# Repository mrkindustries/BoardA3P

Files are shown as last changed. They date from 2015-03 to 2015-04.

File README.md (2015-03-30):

BoardA3PU
=============

## Arduino-compatible FPGA board

## Schematic
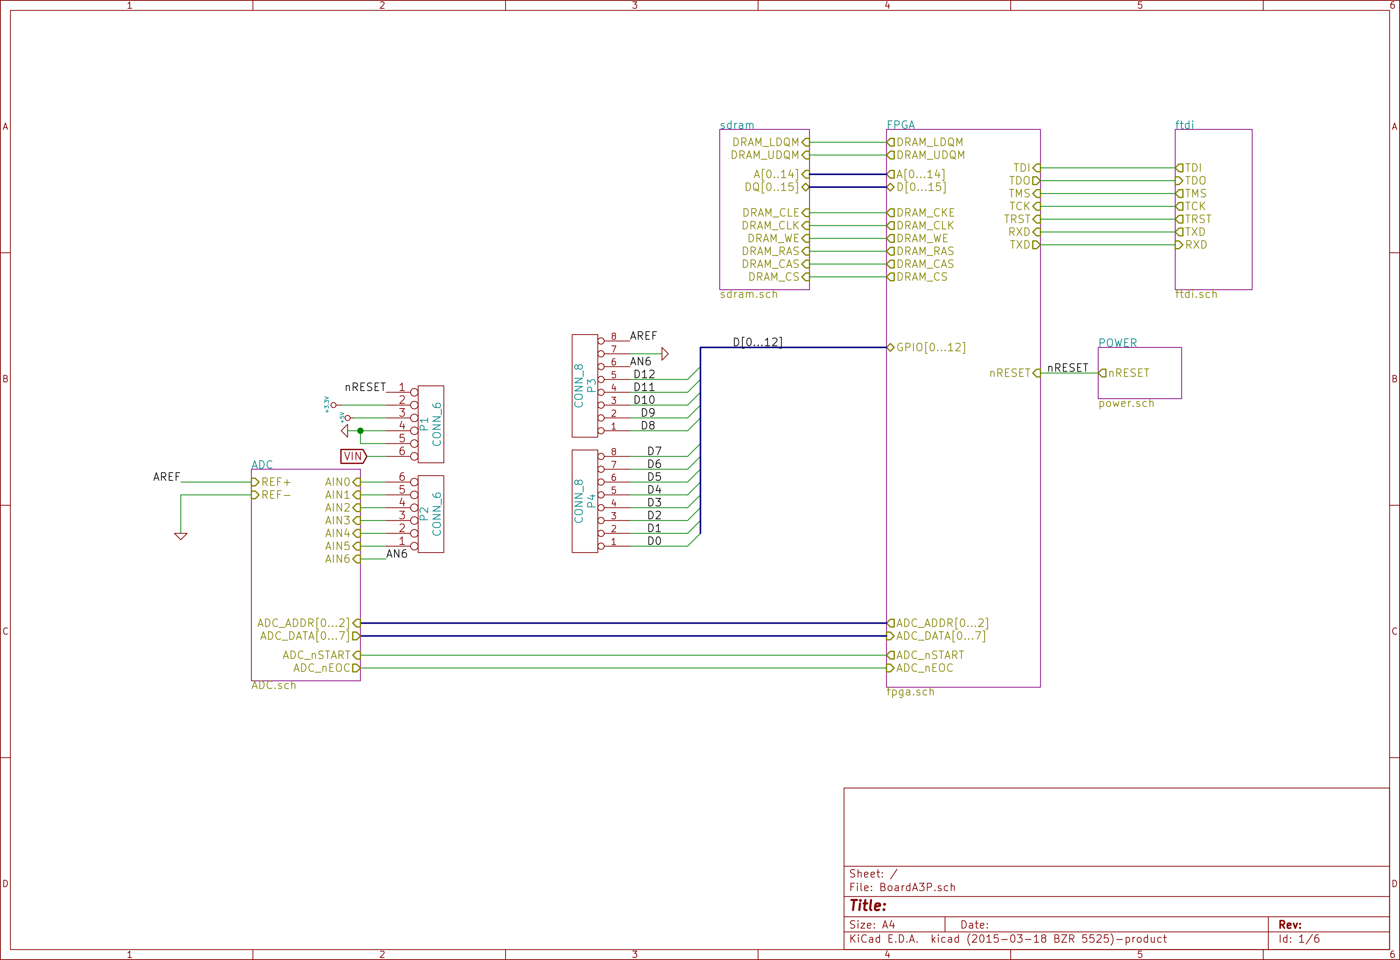
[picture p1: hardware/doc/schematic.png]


## 3D views
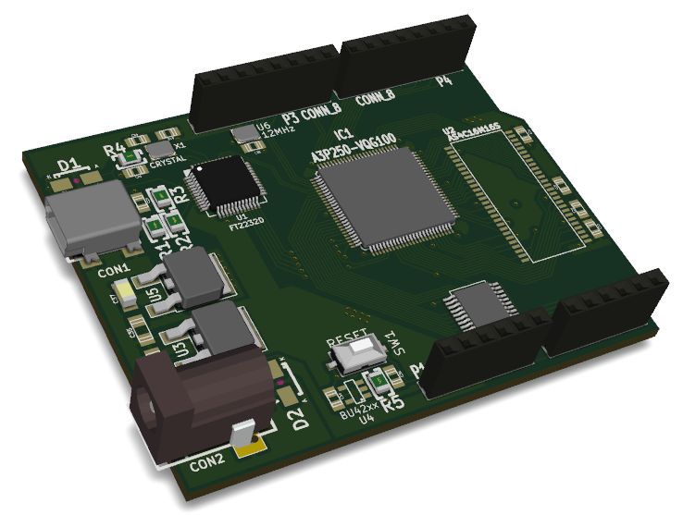
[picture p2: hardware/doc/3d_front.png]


This board was designed using kicad, you can find the CAD files in the /hardware/design folder
http://www.kicad-pcb.org

Download the schematic

[schematic.pdf](/hardware/doc/schematic.pdf?raw=true)

**Warning:** untested until the first prototype arrives

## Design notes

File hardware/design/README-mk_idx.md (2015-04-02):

mk_idx.py
=========

Create index HTML file with references to sheets

Required
========

  * python 2.7 
  * inkscape

Usage
=====

  * Export schematic as svg files
  * Run ```python mk_idx.py <top-schematic.sch>``` into exported image directory

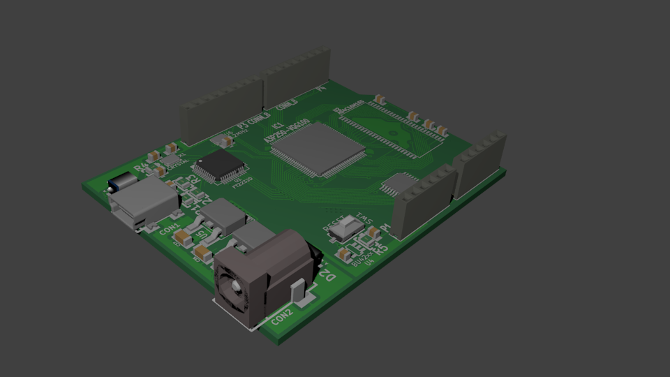
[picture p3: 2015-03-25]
hardware/doc/BoardA3P.png

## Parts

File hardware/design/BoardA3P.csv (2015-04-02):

Reference | Value | Footprint | Unit Price | Digi Code
P1 | PPTC081LFBN-RC | Connect:SIL-6 | 0,68 | S7004-ND
P3 | PPTC081LFBN-RC | Connect:SIL-8 | 0,68 | S7004-ND
P4 | PPTC081LFBN-RC | Connect:SIL-8 | 0,86 | S7006-ND
P2 | PPTC081LFBN-RC | Connect:SIL-6 | 0,86 | S7006-ND
IC1 | A3PN250-VQG100 | SMD_Packages:VQFP100 | 14,96 | 1100-1042-ND
C3 | 100n | Capacitors_SMD:c_0805 | 0,1 | 1276-1007-1-ND
C4 | 100n | Capacitors_SMD:c_0805 | 0,1 | 1276-1007-1-ND
C5 | 100n | Capacitors_SMD:c_0805 | 0,1 | 1276-1007-1-ND
C6 | 100n | Capacitors_SMD:c_0805 | 0,1 | 1276-1007-1-ND
C7 | 100n | Capacitors_SMD:c_0805 | 0,1 | 1276-1007-1-ND
C8 | 100n | Capacitors_SMD:c_0805 | 0,1 | 1276-1007-1-ND
C10 | 100n | Capacitors_SMD:c_0805 | 0,1 | 1276-1007-1-ND
C11 | 100n | Capacitors_SMD:c_0805 | 0,1 | 1276-1007-1-ND
C12 | 100n | Capacitors_SMD:c_0805 | 0,1 | 1276-1007-1-ND
C13 | 100n | Capacitors_SMD:c_0805 | 0,1 | 1276-1007-1-ND
C14 | 10n | Capacitors_SMD:c_0805 | 0,1 | 490-1664-1-ND
C15 | 10n | Capacitors_SMD:c_0805 | 0,1 | 490-1664-1-ND
C16 | 10n | Capacitors_SMD:c_0805 | 0,1 | 490-1664-1-ND
C17 | 10n | Capacitors_SMD:c_0805 | 0,1 | 490-1664-1-ND
C9 | 100n | Capacitors_SMD:c_0805 | 0,1 | 1276-1007-1-ND
C2 | 10n | Capacitors_SMD:c_0805 | 0,1 | 490-1664-1-ND
C1 | 33u | Capacitors_SMD:c_0805 | 0,88 | 445-4060-1-ND
U6 | 12MHz | local:OSC_2x2p5
C38 | 100n | Capacitors_SMD:c_0805 | 0,1 | 1276-1007-1-ND
U1 | FT2232D | Housings_QFP:lqfp-48 | 6,99 | 768-1010-1-ND
CON1 | USB-MINI-B | Connect:USB_MINI_B
C20 | 33n | Capacitors_SMD:c_0805 | 0,1 | 1276-1796-1-ND
C23 | 100n | Capacitors_SMD:c_0805 | 0,1 | 1276-1007-1-ND
C24 | 100n | Capacitors_SMD:c_0805 | 0,1 | 1276-1007-1-ND
C22 | 10u | Capacitors_SMD:c_1206 | 0,19 | 399-1299-1-ND
R4 | 470R | Resistors_SMD:Resistor_SMD0805_ReflowWave | 0,1
C21 | 100n | Capacitors_SMD:c_0805 | 0,1 | 1276-1007-1-ND
C25 | 100n | Capacitors_SMD:c_0805 | 0,1 | 1276-1007-1-ND
R1 | 27R | Resistors_SMD:Resistor_SMD0805_ReflowWave | 0,1
R2 | 27R | Resistors_SMD:Resistor_SMD0805_ReflowWave | 0,1
R3 | 1K5 | Resistors_SMD:Resistor_SMD0805_ReflowWave | 0,1
X1 | 6Mhz | Crystals_Oscillators_SMD:crystal_FA238-TSX3225
C18 | 33n | Capacitors_SMD:c_0805 | 0,1 | 1276-1796-1-ND
C19 | 33n | Capacitors_SMD:c_0805 | 0,1 | 1276-1796-1-ND
D1 | S1G | Diodes_SMD:Diode-SMA_Standard | 0,42
U2 | AS4C16M16S | local:TSOP_II_54 | 2,84 | 1450-1145-ND
C26 | 100n | Capacitors_SMD:c_0805 | 0,1 | 1276-1007-1-ND
C27 | 100n | Capacitors_SMD:c_0805 | 0,1 | 1276-1007-1-ND
C28 | 100n | Capacitors_SMD:c_0805 | 0,1 | 1276-1007-1-ND
C29 | 100n | Capacitors_SMD:c_0805 | 0,1 | 1276-1007-1-ND
C30 | 100n | Capacitors_SMD:c_0805 | 0,1 | 1276-1007-1-ND
C31 | 100n | Capacitors_SMD:c_0805 | 0,1 | 1276-1007-1-ND
C32 | 100n | Capacitors_SMD:c_0805 | 0,1 | 1276-1007-1-ND
CON2 | BARREL_JACK | Connect:BARREL_JACK
U5 | NCP1117ST15T3G | SMD_Packages:DPAK2 | 0,45 | NCP1117DT15RKGOSCT-ND
U3 | NCP1117ST33T3G | SMD_Packages:DPAK2 | 0,49 | NCP1117DT33RKGOSCT-ND
C35 | 4u7 | Capacitors_SMD:c_1206 | 0,2 | 1276-1191-1-ND
C37 | 4u7 | Capacitors_SMD:c_1206 | 0,2 | 1276-1191-1-ND
C33 | 10u | Capacitors_SMD:c_1206 | 0,19 | 399-1299-1-ND
U4 | BU42xx | local:SSOP-5
C34 | 100n | Capacitors_SMD:c_0805 | 0,1 | 1276-1007-1-ND
SW1 | RESET | switchs:smd_push
R5 | 10k | Resistors_SMD:Resistor_SMD0805_ReflowWave | 0,1
C36 | 1u | Capacitors_SMD:c_0805 | 0,1 | 1276-1246-1-ND
D2 | S1G | Diodes_SMD:Diode-SMA_Standard | 0,42
U7 | MAX117 | SMD_Packages:SSOP28 | 7,03 | MAX117CAI+-ND
C40 | 100n | Capacitors_SMD:c_0805 | 0,1 | 1276-1007-1-ND
 |  |  | 42,24

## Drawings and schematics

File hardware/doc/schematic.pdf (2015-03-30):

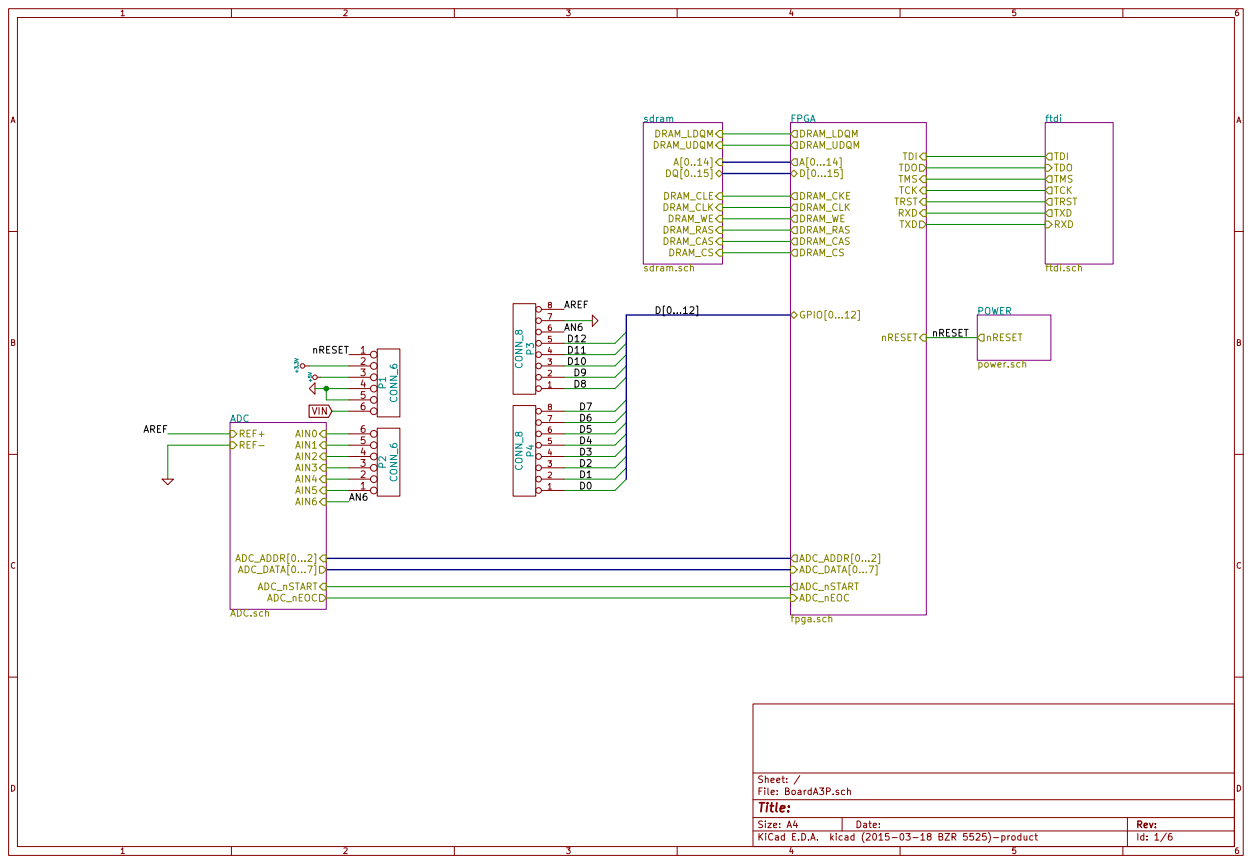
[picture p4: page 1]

ftdi ftdi.sch TCK

Id: 1/6 Title: File: BoardA3P.sch Sheet: /

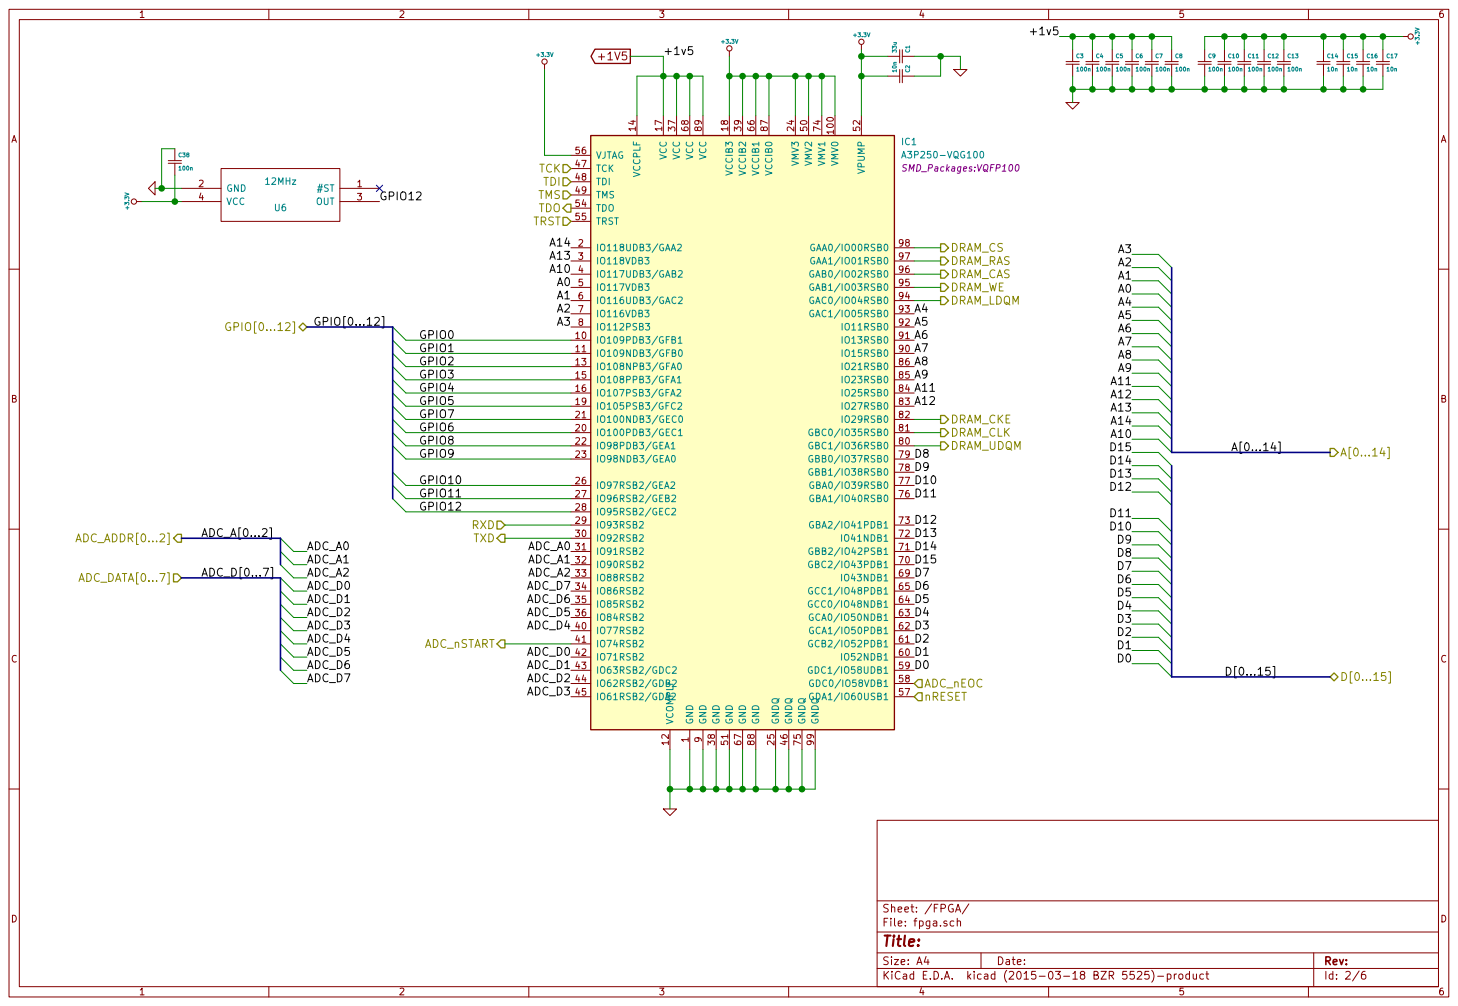
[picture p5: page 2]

File: fpga.sch Sheet: /FPGA/ GND

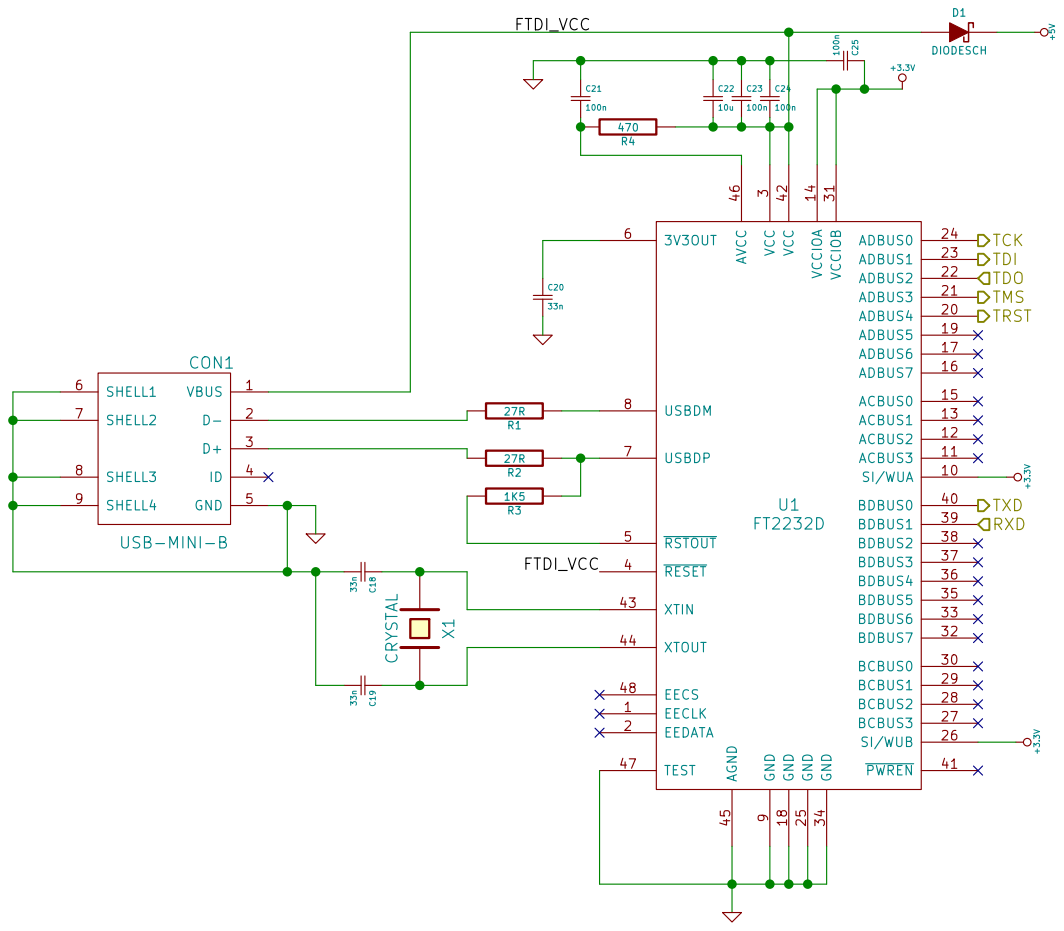
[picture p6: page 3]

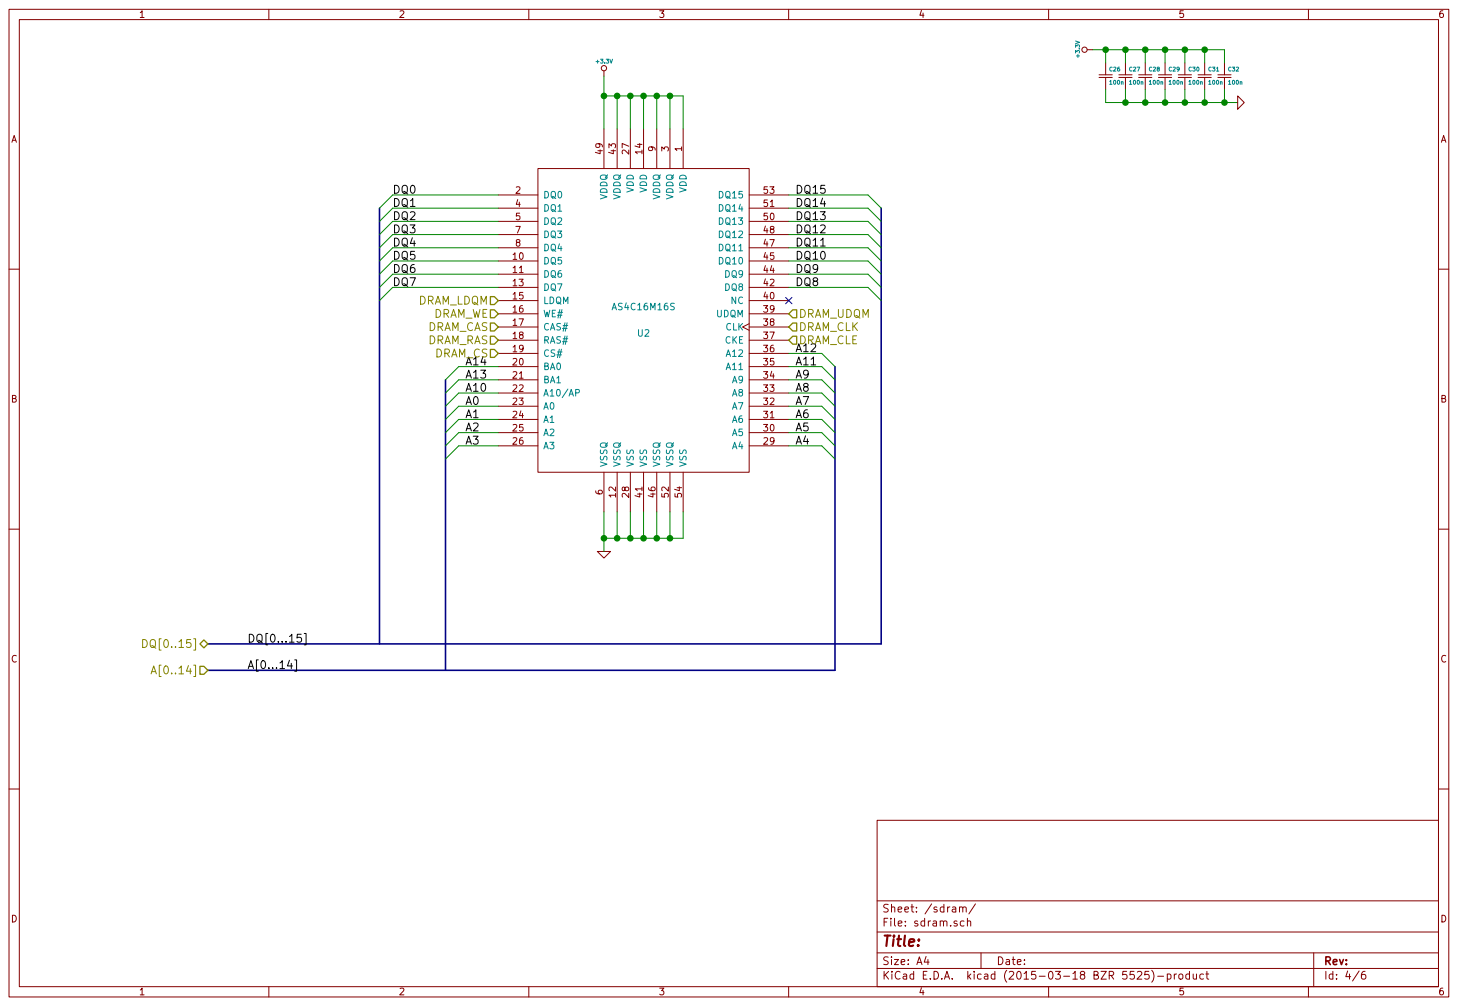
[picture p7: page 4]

9 DQ5 10 BA0 20 A5 30 NC 40 DQ13 50 DQ6 11 BA1 21 A6 31 VSS 41 DQ14 51 VSSQ 12 A10/AP 22 A7 32 DQ8 42 VSSQ 52 DQ7 13 A0 23 A8 33 VDDQ 43 DQ15 VDD 53 14 A1 24 A9 34 DQ9 44 VSS 54

Id: 4/6 Title: File: sdram.sch Sheet: /sdram/ VDD

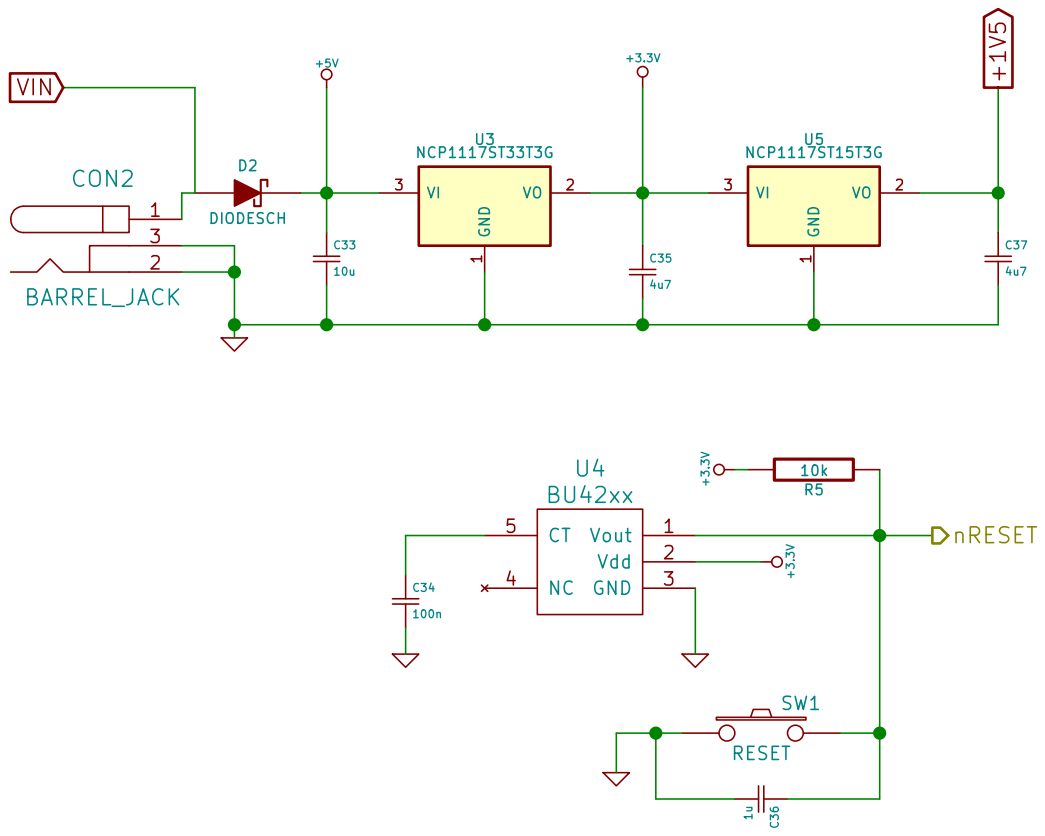
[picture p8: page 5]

File: power.sch Sheet: /POWER/
Id: 5/6 Title:

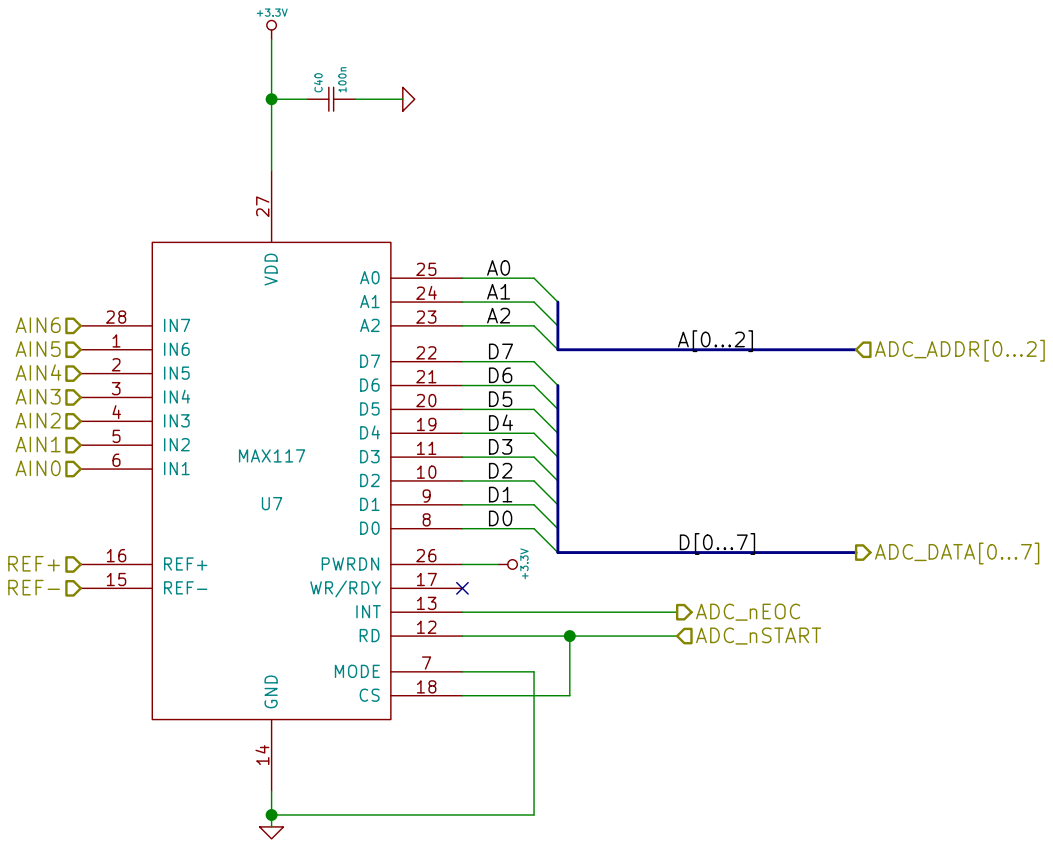
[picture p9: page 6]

Id: 6/6 Title: File: ADC.sch Sheet: /ADC/

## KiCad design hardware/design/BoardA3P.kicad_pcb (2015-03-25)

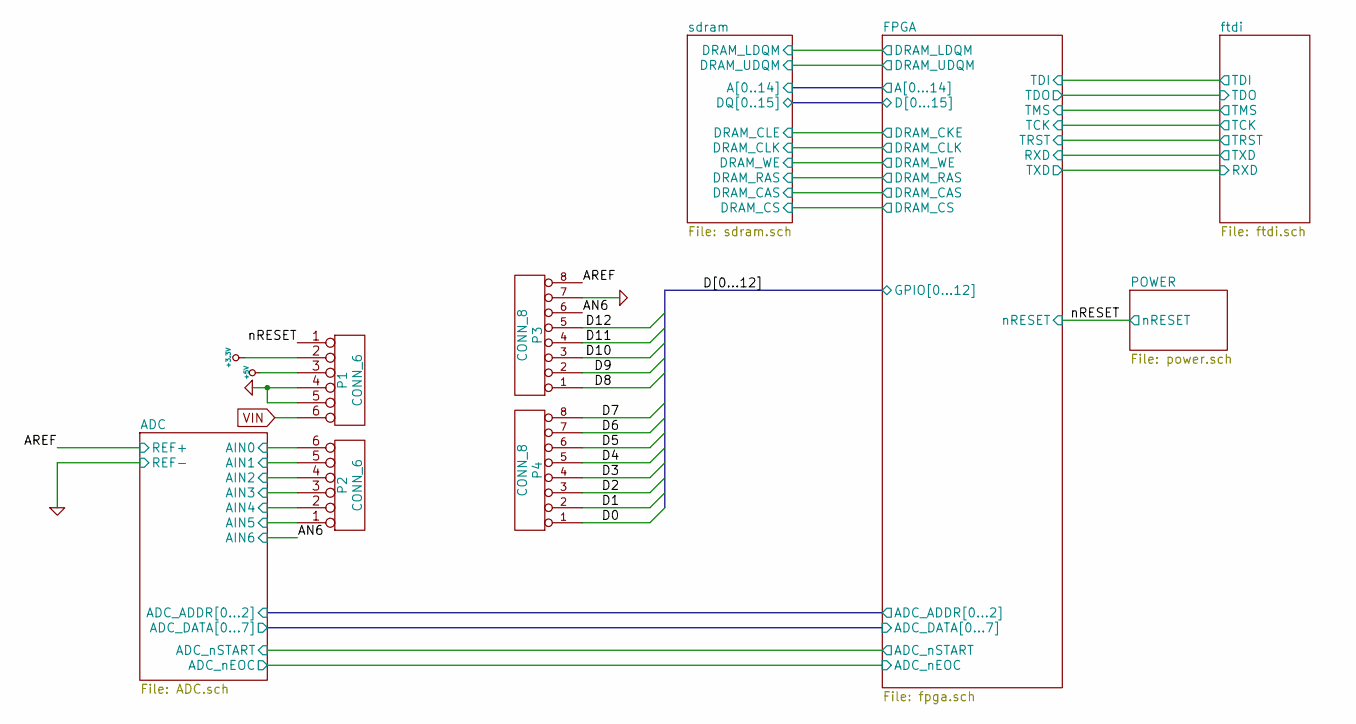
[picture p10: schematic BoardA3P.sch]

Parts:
P1, P2: CONN_6; SIL-6
P3, P4: CONN_8; SIL-8

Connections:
+3.3V: P1.2; also elsewhere on the board
+5V: P1.3; also elsewhere on the board
/ADC/AIN0: P2.6; also elsewhere on the board
/ADC/AIN1: P2.5; also elsewhere on the board
/ADC/AIN2: P2.4; also elsewhere on the board
/ADC/AIN3: P2.3; also elsewhere on the board
/ADC/AIN4: P2.2; also elsewhere on the board
/ADC/AIN5: P2.1; also elsewhere on the board
/ADC/AIN6: P3.6; also elsewhere on the board
/ADC/REF+: P3.8; also elsewhere on the board
/D0: P4.1; also elsewhere on the board
/D1: P4.2; also elsewhere on the board
/D2: P4.3; also elsewhere on the board
/D3: P4.4; also elsewhere on the board
/D4: P4.5; also elsewhere on the board
/D5: P4.6; also elsewhere on the board
/D6: P4.7; also elsewhere on the board
/D7: P4.8; also elsewhere on the board
/D8: P3.1; also elsewhere on the board
/D9: P3.2; also elsewhere on the board
/D10: P3.3; also elsewhere on the board
/D11: P3.4; also elsewhere on the board
/D12: P3.5; also elsewhere on the board
/FPGA/nRESET: P1.1; also elsewhere on the board
GND: P1.4, P1.5, P3.7; also elsewhere on the board
VIN: P1.6; also elsewhere on the board

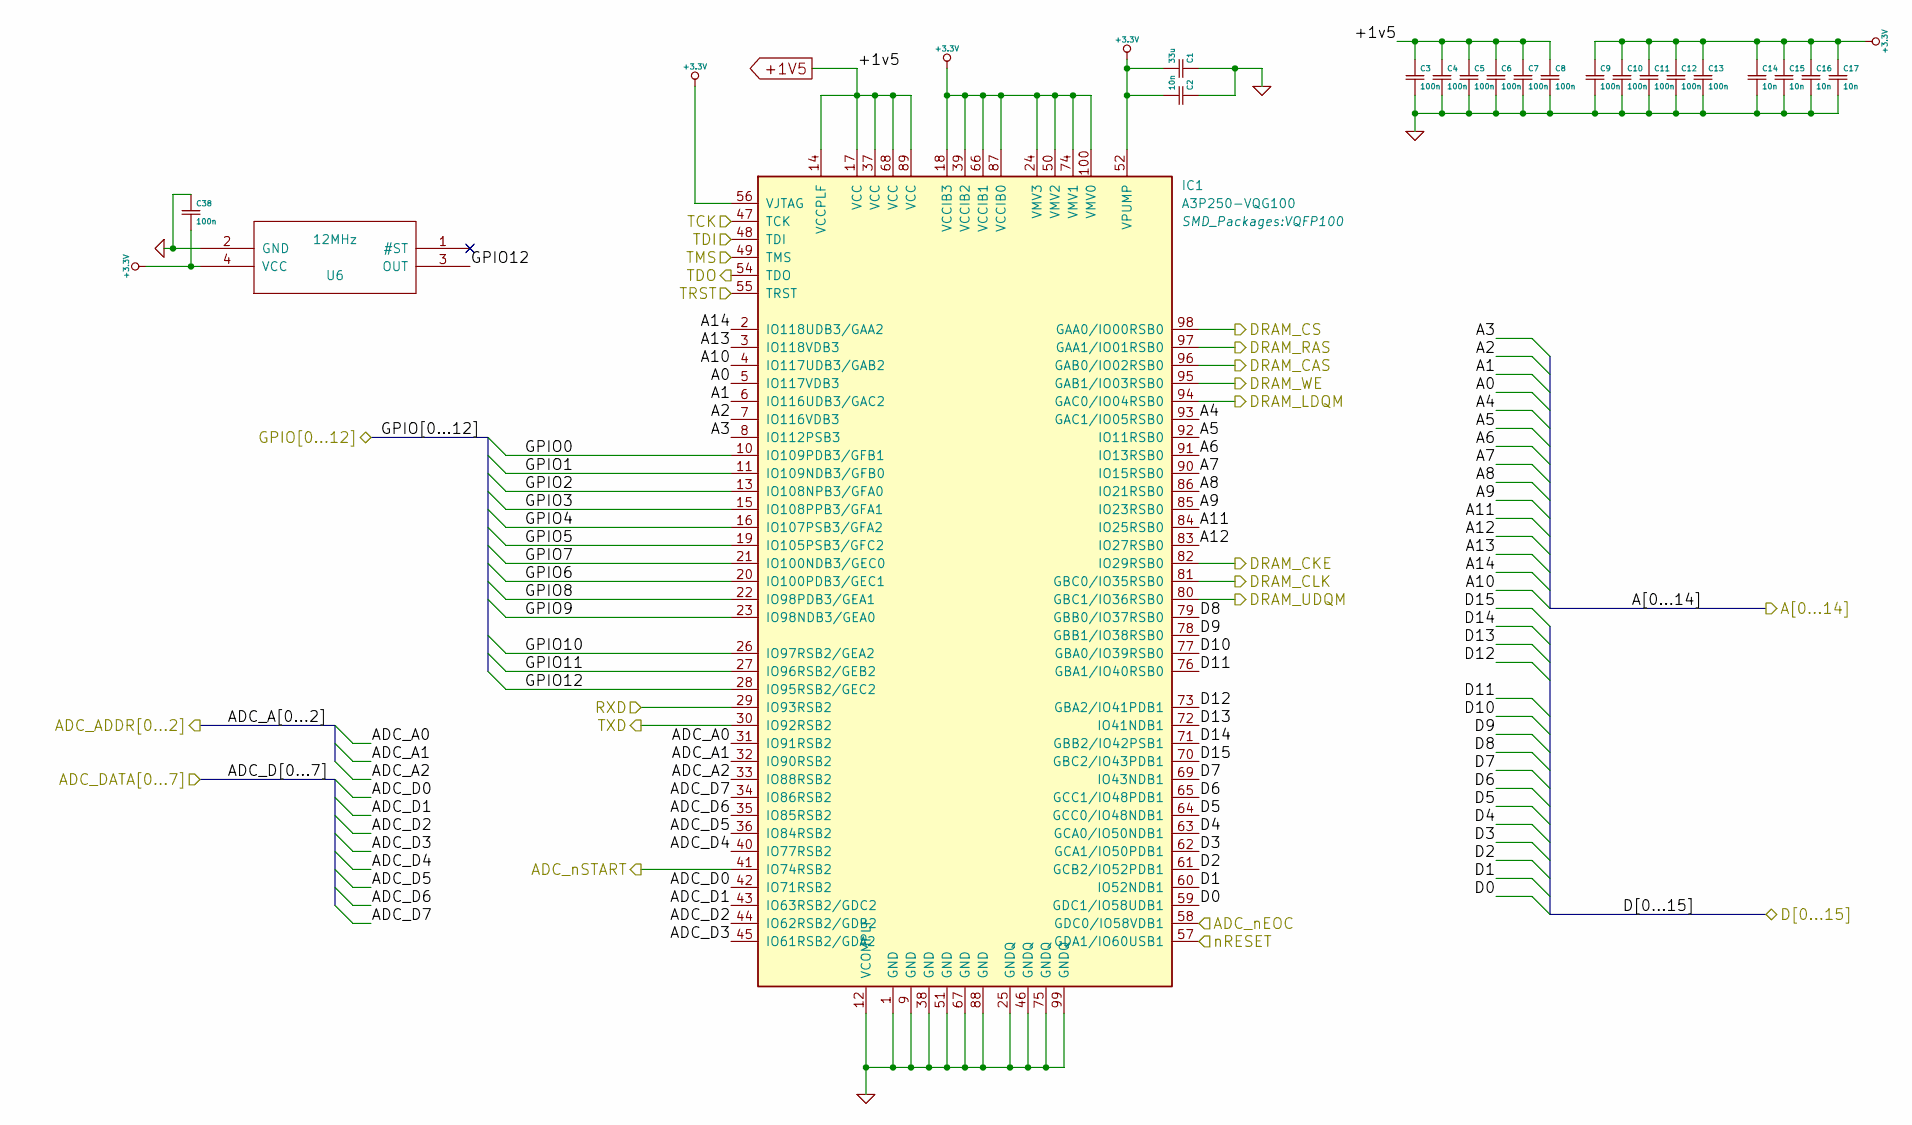
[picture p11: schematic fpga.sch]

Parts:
C1: 33u; c_0805
C2, C14, C15, C16, C17: 10n; c_0805
C3, C4, C5, C6, C7, C8, C9, C10, C11, C12, C13, C38: 100n; c_0805
IC1: A3P250-VQG100; VQFP100
U6: 12MHz; OSC_2x2p5

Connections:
+1V5: C3.1, C4.1, C5.1, C6.1, C7.1, C8.1, IC1.14 (VCCPLF), IC1.17 (VCC), IC1.37 (VCC), IC1.68 (VCC), IC1.89 (VCC); also elsewhere on the board
+3.3V: C1.2, C2.2, C9.1, C10.1, C11.1, C12.1, C13.1, C14.1, C15.1, C16.1, C17.1, C38.2, IC1.18 (VCCIB3), IC1.24 (VMV3), IC1.39 (VCCIB2), IC1.50 (VMV2), IC1.52 (VPUMP), IC1.56 (VJTAG), IC1.66 (VCCIB1), IC1.74 (VMV1), IC1.87 (VCCIB0), IC1.100 (VMV0), U6.4 (VCC); also elsewhere on the board
/ADC/A0: IC1.31 (IO91RSB2); also elsewhere on the board
/ADC/A1: IC1.32 (IO90RSB2); also elsewhere on the board
/ADC/A2: IC1.33 (IO88RSB2); also elsewhere on the board
/ADC/ADC_nEOC: IC1.58 (GDC0/IO58VDB1); also elsewhere on the board
/ADC/ADC_nSTART: IC1.41 (IO74RSB2); also elsewhere on the board
/D0: IC1.10 (IO109PDB3/GFB1); also elsewhere on the board
/D1: IC1.11 (IO109NDB3/GFB0); also elsewhere on the board
/D2: IC1.13 (IO108NPB3/GFA0); also elsewhere on the board
/D3: IC1.15 (IO108PPB3/GFA1); also elsewhere on the board
/D4: IC1.16 (IO107PSB3/GFA2); also elsewhere on the board
/D5: IC1.19 (IO105PSB3/GFC2); also elsewhere on the board
/D6: IC1.20 (IO100PDB3/GEC1); also elsewhere on the board
/D7: IC1.21 (IO100NDB3/GEC0); also elsewhere on the board
/D8: IC1.22 (IO98PDB3/GEA1); also elsewhere on the board
/D9: IC1.23 (IO98NDB3/GEA0); also elsewhere on the board
/D10: IC1.26 (IO97RSB2/GEA2); also elsewhere on the board
/D11: IC1.27 (IO96RSB2/GEB2); also elsewhere on the board
/D12: IC1.28 (IO95RSB2/GEC2), U6.3 (OUT); also elsewhere on the board
/FPGA/A0: IC1.5 (IO117VDB3); also elsewhere on the board
/FPGA/A1: IC1.6 (IO116UDB3/GAC2); also elsewhere on the board
/FPGA/A2: IC1.7 (IO116VDB3); also elsewhere on the board
/FPGA/A3: IC1.8 (IO112PSB3); also elsewhere on the board
/FPGA/A4: IC1.93 (GAC1/IO05RSB0); also elsewhere on the board
/FPGA/A5: IC1.92 (IO11RSB0); also elsewhere on the board
/FPGA/A6: IC1.91 (IO13RSB0); also elsewhere on the board
/FPGA/A7: IC1.90 (IO15RSB0); also elsewhere on the board
/FPGA/A8: IC1.86 (IO21RSB0); also elsewhere on the board
/FPGA/A9: IC1.85 (IO23RSB0); also elsewhere on the board
/FPGA/A10: IC1.4 (IO117UDB3/GAB2); also elsewhere on the board
/FPGA/A11: IC1.84 (IO25RSB0); also elsewhere on the board
/FPGA/A12: IC1.83 (IO27RSB0); also elsewhere on the board
/FPGA/A13: IC1.3 (IO118VDB3); also elsewhere on the board
/FPGA/A14: IC1.2 (IO118UDB3/GAA2); also elsewhere on the board
/FPGA/ADC_D0: IC1.42 (IO71RSB2); also elsewhere on the board
/FPGA/ADC_D1: IC1.43 (IO63RSB2/GDC2); also elsewhere on the board
/FPGA/ADC_D2: IC1.44 (IO62RSB2/GDB2); also elsewhere on the board
/FPGA/ADC_D3: IC1.45 (IO61RSB2/GDA2); also elsewhere on the board
/FPGA/ADC_D4: IC1.40 (IO77RSB2); also elsewhere on the board
/FPGA/ADC_D5: IC1.36 (IO84RSB2); also elsewhere on the board
/FPGA/ADC_D6: IC1.35 (IO85RSB2); also elsewhere on the board
/FPGA/ADC_D7: IC1.34 (IO86RSB2); also elsewhere on the board
/FPGA/D0: IC1.59 (GDC1/IO58UDB1); also elsewhere on the board
/FPGA/D1: IC1.60 (IO52NDB1); also elsewhere on the board
/FPGA/D2: IC1.61 (GCB2/IO52PDB1); also elsewhere on the board
/FPGA/D3: IC1.62 (GCA1/IO50PDB1); also elsewhere on the board
/FPGA/D4: IC1.63 (GCA0/IO50NDB1); also elsewhere on the board
/FPGA/D5: IC1.64 (GCC0/IO48NDB1); also elsewhere on the board
/FPGA/D6: IC1.65 (GCC1/IO48PDB1); also elsewhere on the board
/FPGA/D7: IC1.69 (IO43NDB1); also elsewhere on the board
/FPGA/D8: IC1.79 (GBB0/IO37RSB0); also elsewhere on the board
/FPGA/D9: IC1.78 (GBB1/IO38RSB0); also elsewhere on the board
/FPGA/D10: IC1.77 (GBA0/IO39RSB0); also elsewhere on the board
/FPGA/D11: IC1.76 (GBA1/IO40RSB0); also elsewhere on the board
/FPGA/D12: IC1.73 (GBA2/IO41PDB1); also elsewhere on the board
/FPGA/D13: IC1.72 (IO41NDB1); also elsewhere on the board
/FPGA/D14: IC1.71 (GBB2/IO42PSB1); also elsewhere on the board
/FPGA/D15: IC1.70 (GBC2/IO43PDB1); also elsewhere on the board
/FPGA/DRAM_CAS: IC1.96 (GAB0/IO02RSB0); also elsewhere on the board
/FPGA/DRAM_CKE: IC1.82 (IO29RSB0); also elsewhere on the board
/FPGA/DRAM_CLK: IC1.81 (GBC0/IO35RSB0); also elsewhere on the board
/FPGA/DRAM_CS: IC1.98 (GAA0/IO00RSB0); also elsewhere on the board
/FPGA/DRAM_LDQM: IC1.94 (GAC0/IO04RSB0); also elsewhere on the board
/FPGA/DRAM_RAS: IC1.97 (GAA1/IO01RSB0); also elsewhere on the board
/FPGA/DRAM_UDQM: IC1.80 (GBC1/IO36RSB0); also elsewhere on the board
/FPGA/DRAM_WE: IC1.95 (GAB1/IO03RSB0); also elsewhere on the board
/FPGA/RXD: IC1.29 (IO93RSB2); also elsewhere on the board
/FPGA/TCK: IC1.47 (TCK); also elsewhere on the board
/FPGA/TDI: IC1.48 (TDI); also elsewhere on the board
/FPGA/TDO: IC1.54 (TDO); also elsewhere on the board
/FPGA/TMS: IC1.49 (TMS); also elsewhere on the board
/FPGA/TRST: IC1.55 (TRST); also elsewhere on the board
/FPGA/nRESET: IC1.57 (GDA1/IO60USB1); also elsewhere on the board
/ftdi/RXD: IC1.30 (IO92RSB2); also elsewhere on the board
GND: C1.1, C2.1, C3.2, C4.2, C5.2, C6.2, C7.2, C8.2, C9.2, C10.2, C11.2, C12.2, C13.2, C14.2, C15.2, C16.2, C17.2, C38.1, IC1.1 (GND), IC1.9 (GND), IC1.12 (VCOMPLF), IC1.25 (GNDQ), IC1.38 (GND), IC1.46 (GNDQ), IC1.51 (GND), IC1.67 (GND), IC1.75 (GNDQ), IC1.88 (GND), IC1.99 (GNDQ), U6.2 (GND); also elsewhere on the board

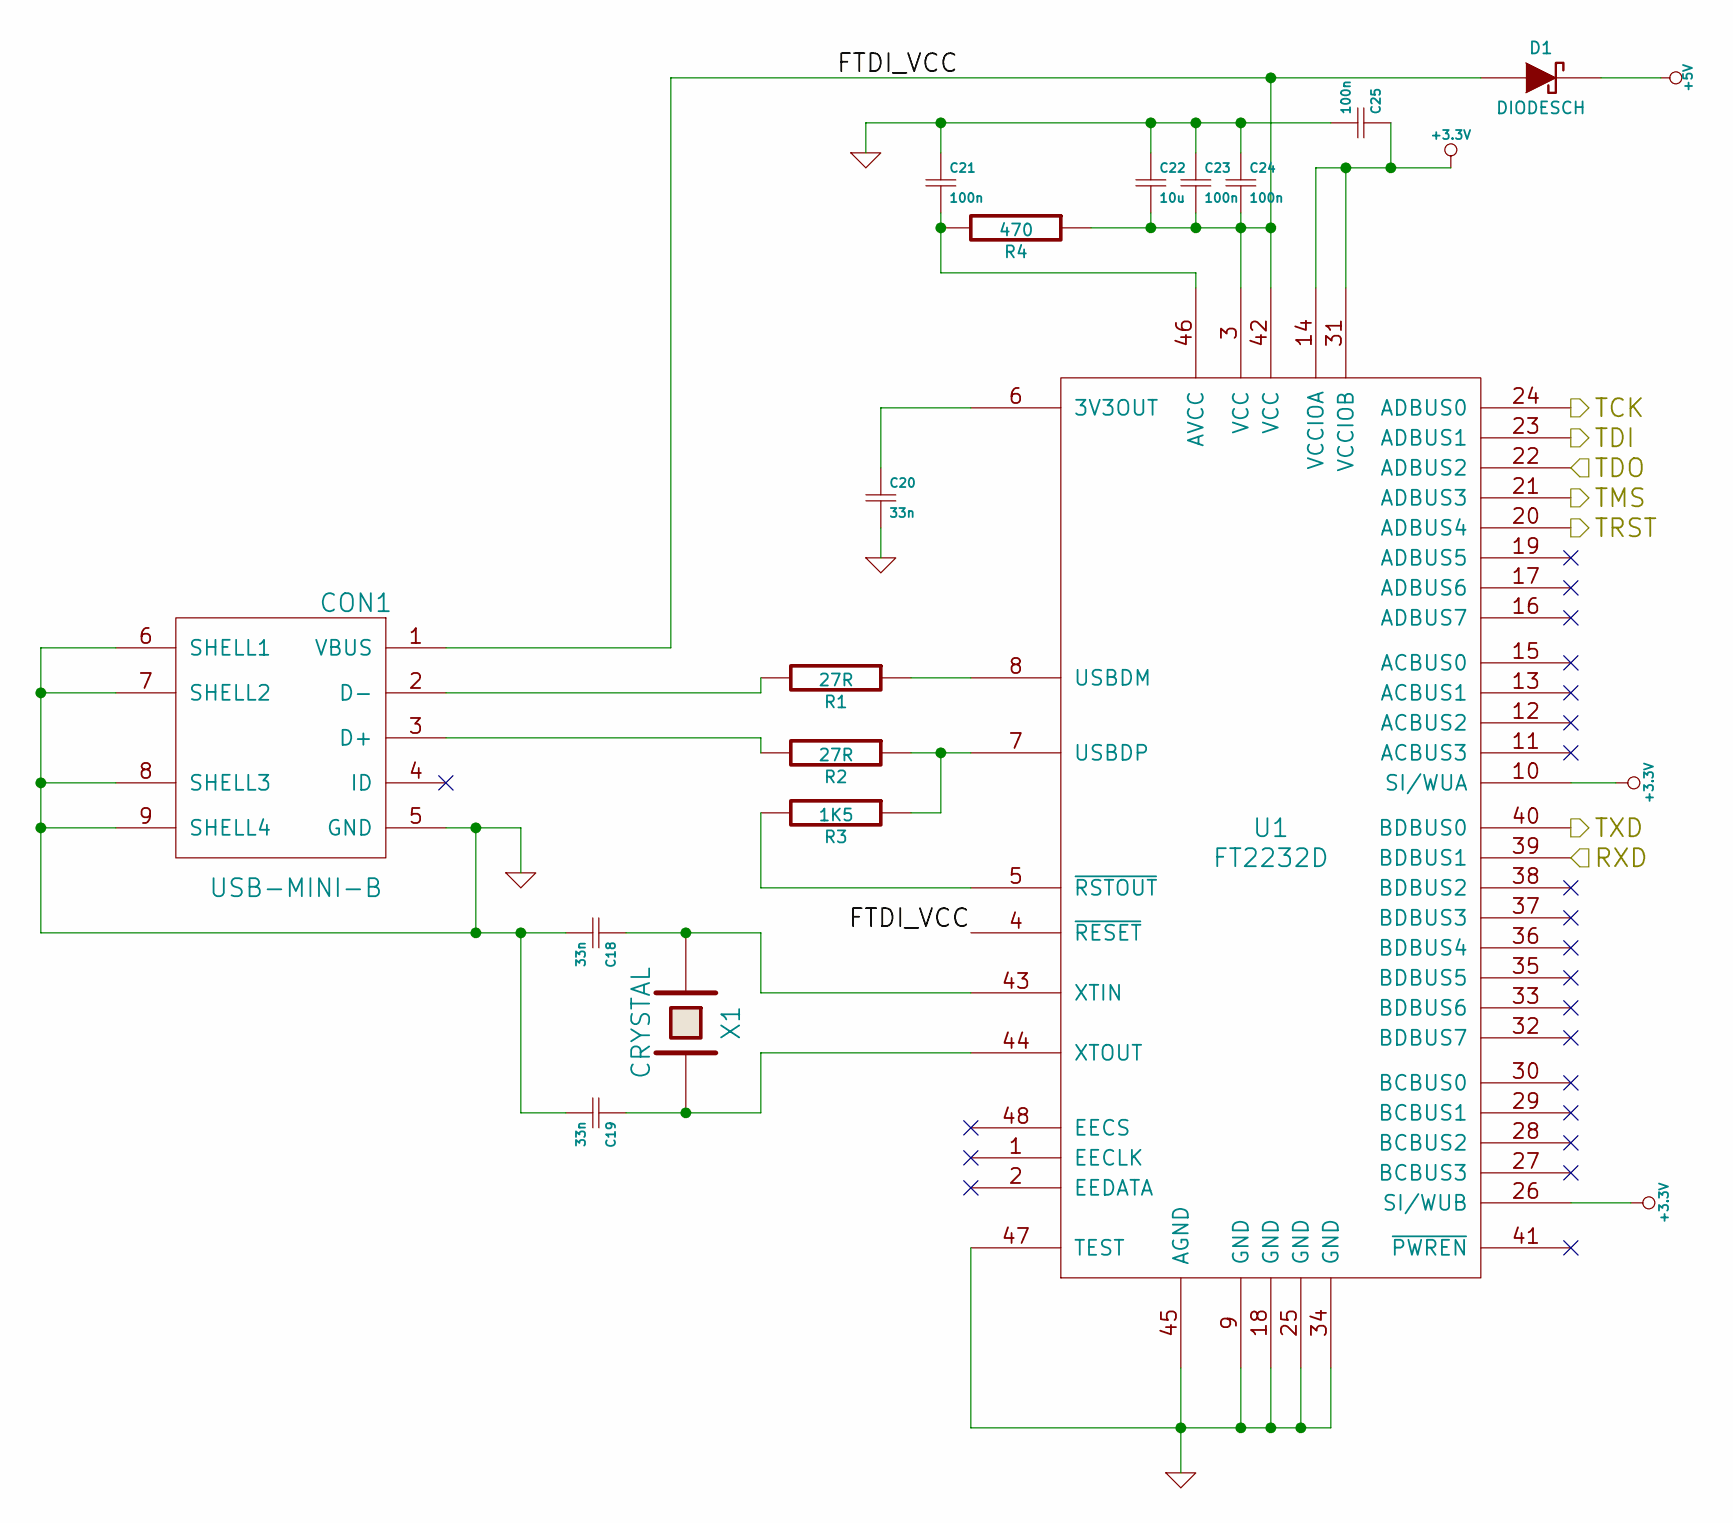
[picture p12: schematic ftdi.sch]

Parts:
C18, C19, C20: 33n; c_0805
C21, C23, C24, C25: 100n; c_0805
C22: 10u; c_1206
CON1: USB-MINI-B; USB_MINI_B
D1: DIODESCH; Diode-SMA_Standard
R1, R2: 27R; Resistor_SMD0805_ReflowWave
R3: 1K5; Resistor_SMD0805_ReflowWave
R4: 470; Resistor_SMD0805_ReflowWave
U1: FT2232D; lqfp-48
X1: CRYSTAL; crystal_FA238-TSX3225

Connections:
+3.3V: C25.1, U1.10 (SI/WUA), U1.14 (VCCIOA), U1.26 (SI/WUB), U1.31 (VCCIOB); also elsewhere on the board
+5V: D1.2 (K); also elsewhere on the board
/FPGA/RXD: U1.40 (BDBUS0); also elsewhere on the board
/FPGA/TCK: U1.24 (ADBUS0); also elsewhere on the board
/FPGA/TDI: U1.23 (ADBUS1); also elsewhere on the board
/FPGA/TDO: U1.22 (ADBUS2); also elsewhere on the board
/FPGA/TMS: U1.21 (ADBUS3); also elsewhere on the board
/FPGA/TRST: U1.20 (ADBUS4); also elsewhere on the board
/ftdi/FTDI_VCC: C22.2, C23.2, C24.2, CON1.1 (VBUS), D1.1 (A), R4.1, U1.3 (VCC), U1.4 (~RESET), U1.42 (VCC)
/ftdi/RXD: U1.39 (BDBUS1); also elsewhere on the board
GND: C18.2, C19.2, C20.2, C21.1, C22.1, C23.1, C24.1, C25.2, CON1.5 (GND), CON1.6 (SHELL1), CON1.7 (SHELL2), CON1.8 (SHELL3), CON1.9 (SHELL4), U1.9 (GND), U1.18 (GND), U1.25 (GND), U1.34 (GND), U1.45 (AGND), U1.47 (TEST); also elsewhere on the board
unnamed: C18.1, U1.43 (XTIN), X1.1
unnamed: C19.1, U1.44 (XTOUT), X1.2
unnamed: C20.1, U1.6 (3V3OUT)
unnamed: C21.2, R4.2, U1.46 (AVCC)
unnamed: CON1.2 (D-), R1.2
unnamed: CON1.3 (D+), R2.2
unnamed: R1.1, U1.8 (USBDM)
unnamed: R2.1, R3.1, U1.7 (USBDP)
unnamed: R3.2, U1.5 (~RSTOUT)

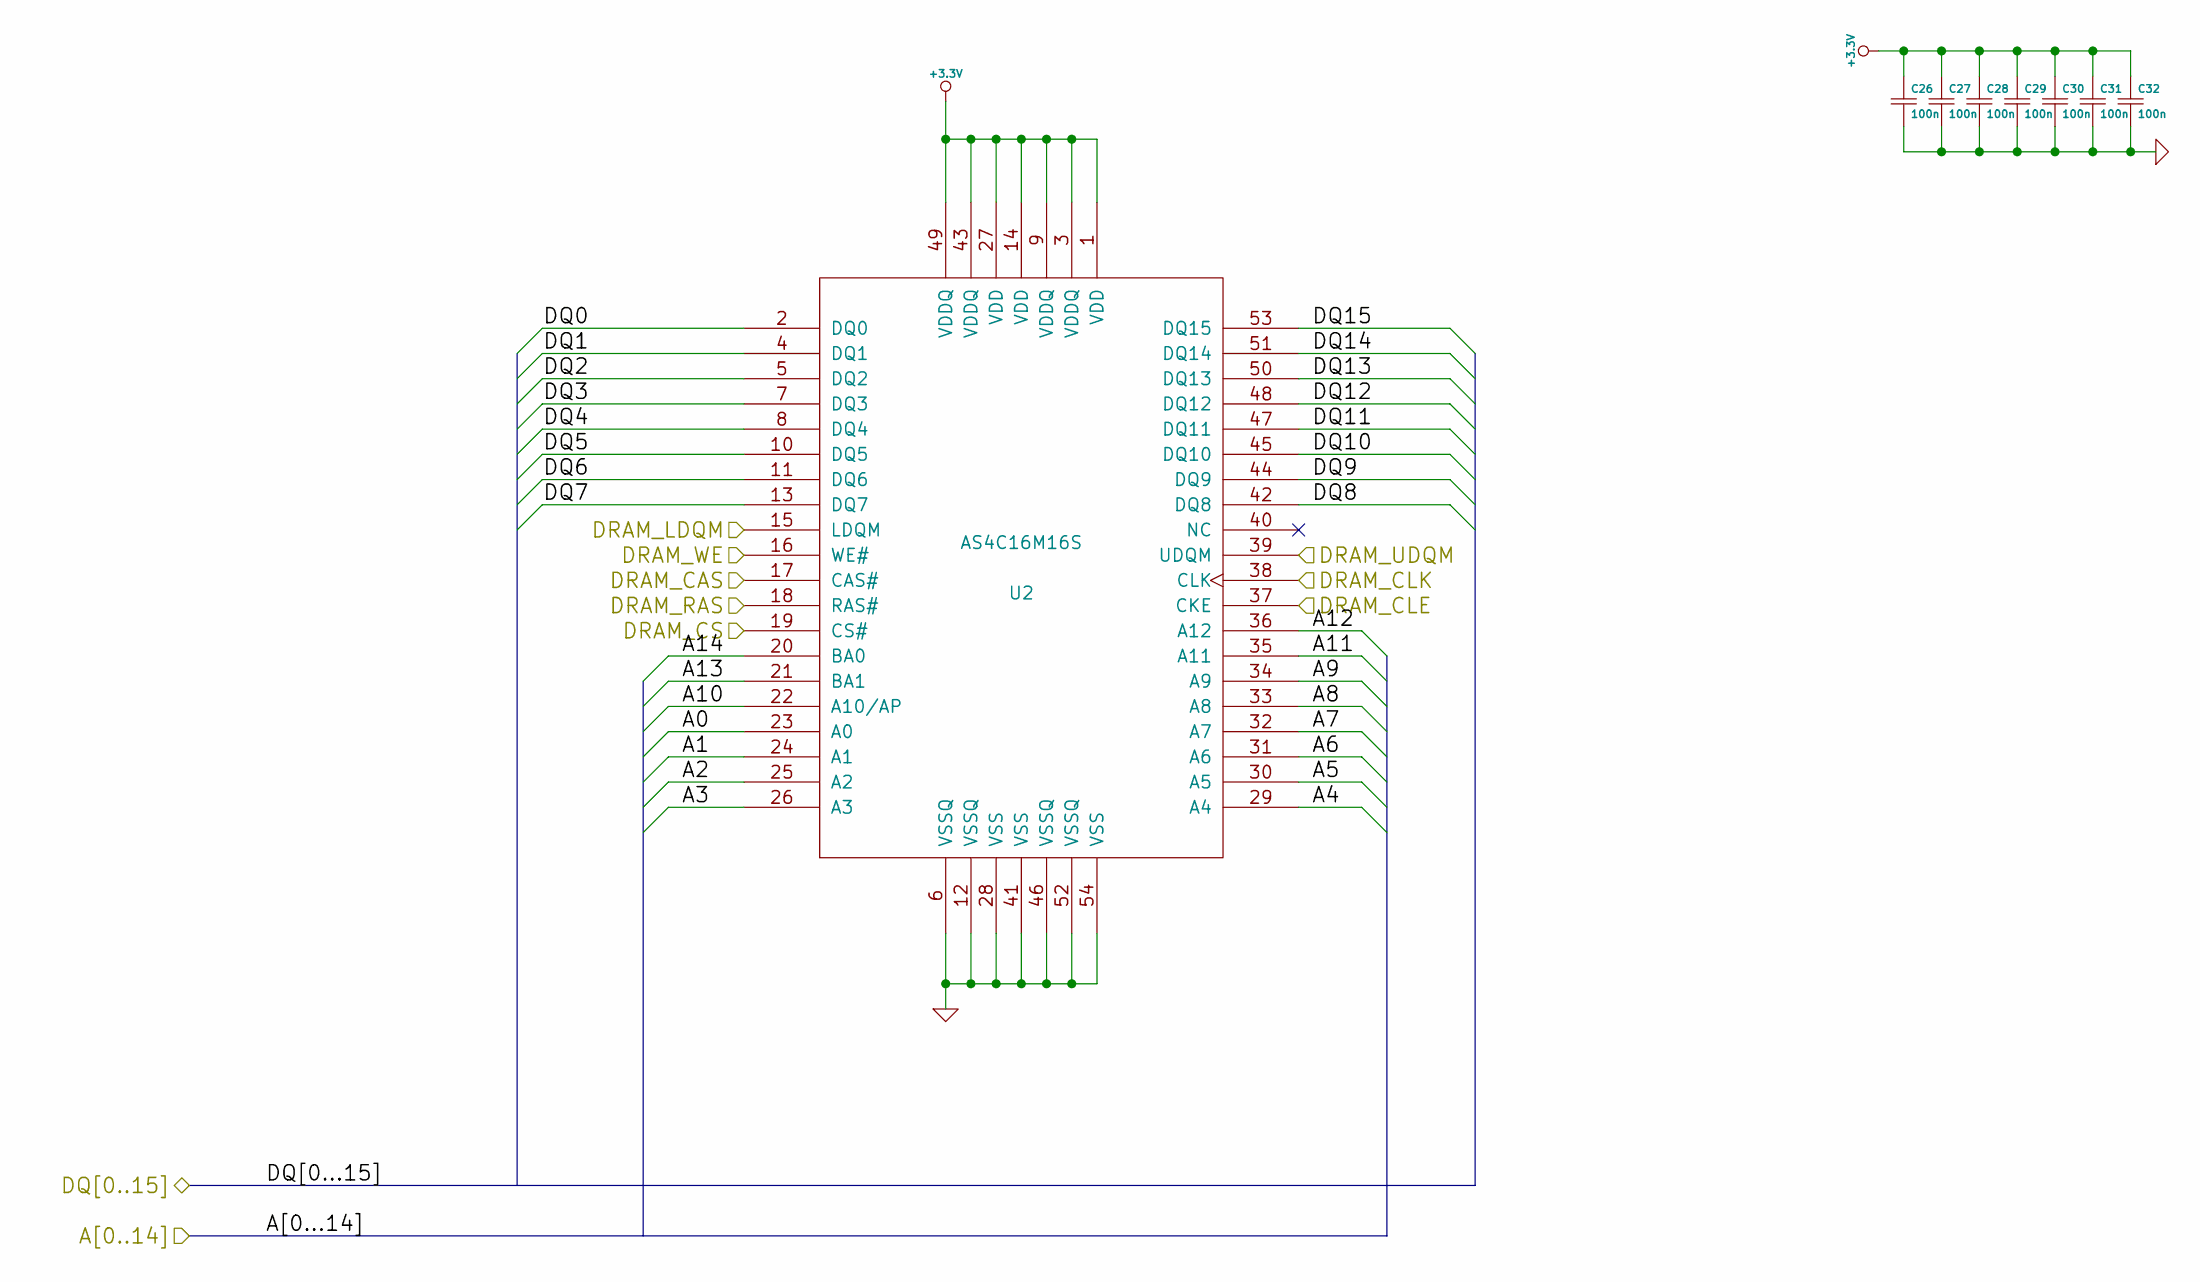
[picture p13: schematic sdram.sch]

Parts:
C26, C27, C28, C29, C30, C31, C32: 100n; c_0805
U2: AS4C16M16S; TSOP_II_54

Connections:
+3.3V: C26.1, C27.1, C28.1, C29.1, C30.1, C31.1, C32.1, U2.1 (VDD), U2.3 (VDDQ), U2.9 (VDDQ), U2.14 (VDD), U2.27 (VDD), U2.43 (VDDQ), U2.49 (VDDQ); also elsewhere on the board
/FPGA/A0: U2.23 (A0); also elsewhere on the board
/FPGA/A1: U2.24 (A1); also elsewhere on the board
/FPGA/A2: U2.25 (A2); also elsewhere on the board
/FPGA/A3: U2.26 (A3); also elsewhere on the board
/FPGA/A4: U2.29 (A4); also elsewhere on the board
/FPGA/A5: U2.30 (A5); also elsewhere on the board
/FPGA/A6: U2.31 (A6); also elsewhere on the board
/FPGA/A7: U2.32 (A7); also elsewhere on the board
/FPGA/A8: U2.33 (A8); also elsewhere on the board
/FPGA/A9: U2.34 (A9); also elsewhere on the board
/FPGA/A10: U2.22 (A10/AP); also elsewhere on the board
/FPGA/A11: U2.35 (A11); also elsewhere on the board
/FPGA/A12: U2.36 (A12); also elsewhere on the board
/FPGA/A13: U2.21 (BA1); also elsewhere on the board
/FPGA/A14: U2.20 (BA0); also elsewhere on the board
/FPGA/D0: U2.2 (DQ0); also elsewhere on the board
/FPGA/D1: U2.4 (DQ1); also elsewhere on the board
/FPGA/D2: U2.5 (DQ2); also elsewhere on the board
/FPGA/D3: U2.7 (DQ3); also elsewhere on the board
/FPGA/D4: U2.8 (DQ4); also elsewhere on the board
/FPGA/D5: U2.10 (DQ5); also elsewhere on the board
/FPGA/D6: U2.11 (DQ6); also elsewhere on the board
/FPGA/D7: U2.13 (DQ7); also elsewhere on the board
/FPGA/D8: U2.42 (DQ8); also elsewhere on the board
/FPGA/D9: U2.44 (DQ9); also elsewhere on the board
/FPGA/D10: U2.45 (DQ10); also elsewhere on the board
/FPGA/D11: U2.47 (DQ11); also elsewhere on the board
/FPGA/D12: U2.48 (DQ12); also elsewhere on the board
/FPGA/D13: U2.50 (DQ13); also elsewhere on the board
/FPGA/D14: U2.51 (DQ14); also elsewhere on the board
/FPGA/D15: U2.53 (DQ15); also elsewhere on the board
/FPGA/DRAM_CAS: U2.17 (CAS#); also elsewhere on the board
/FPGA/DRAM_CKE: U2.37 (CKE); also elsewhere on the board
/FPGA/DRAM_CLK: U2.38 (CLK); also elsewhere on the board
/FPGA/DRAM_CS: U2.19 (CS#); also elsewhere on the board
/FPGA/DRAM_LDQM: U2.15 (LDQM); also elsewhere on the board
/FPGA/DRAM_RAS: U2.18 (RAS#); also elsewhere on the board
/FPGA/DRAM_UDQM: U2.39 (UDQM); also elsewhere on the board
/FPGA/DRAM_WE: U2.16 (WE#); also elsewhere on the board
GND: C26.2, C27.2, C28.2, C29.2, C30.2, C31.2, C32.2, U2.6 (VSSQ), U2.12 (VSSQ), U2.28 (VSS), U2.41 (VSS), U2.46 (VSSQ), U2.52 (VSSQ), U2.54 (VSS); also elsewhere on the board

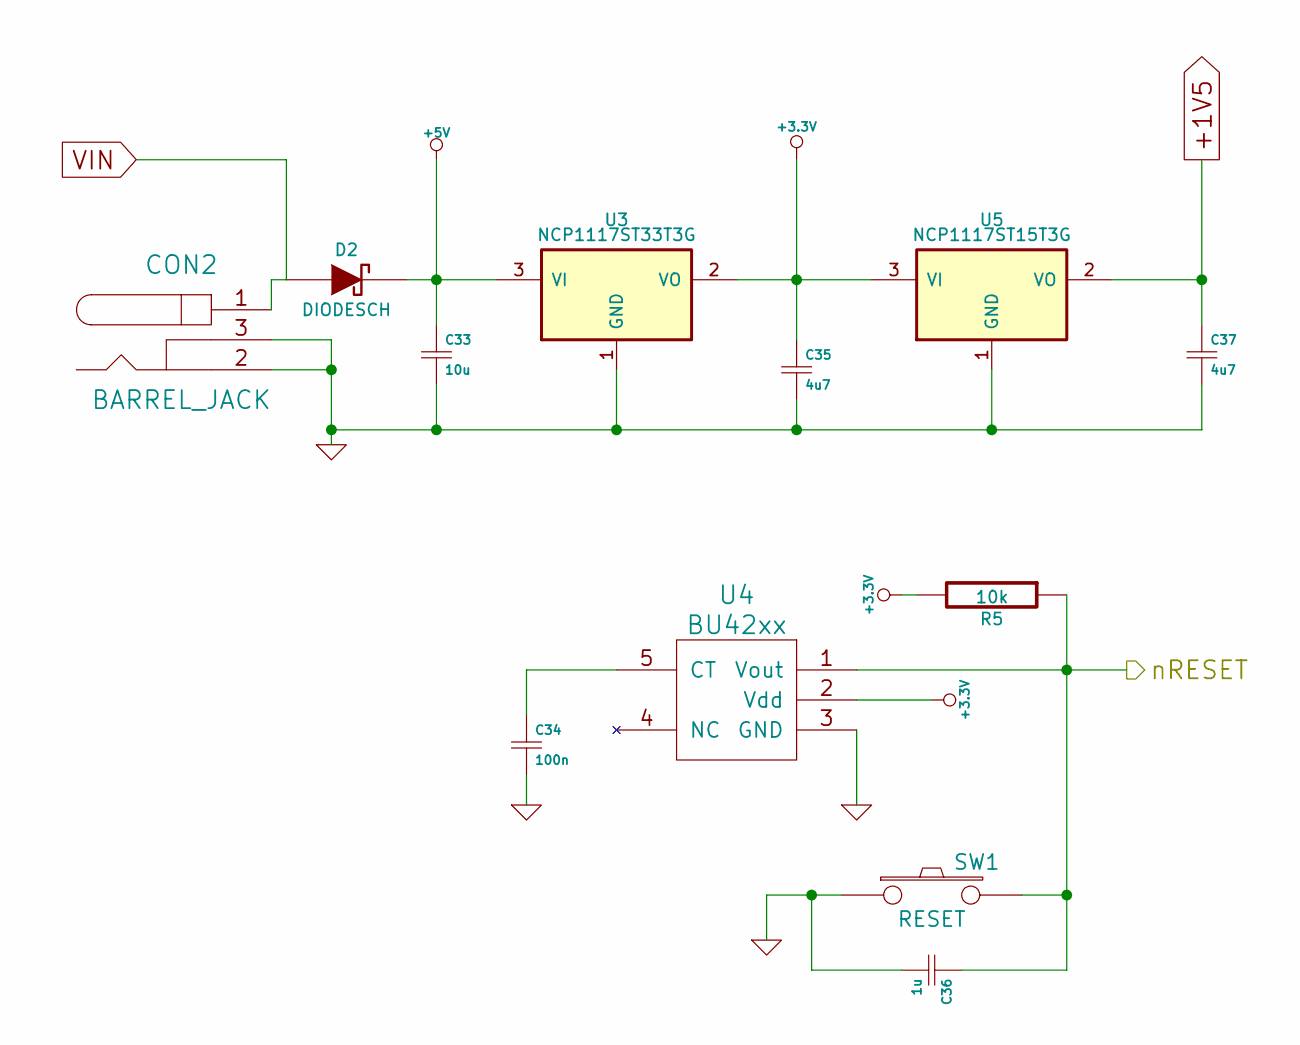
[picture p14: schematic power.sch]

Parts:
C33: 10u; c_1206
C34: 100n; c_0805
C35, C37: 4u7; c_1206
C36: 1u; c_0805
CON2: BARREL_JACK
D2: DIODESCH; Diode-SMA_Standard
R5: 10k; Resistor_SMD0805_ReflowWave
SW1: RESET; smd_push
U3: NCP1117ST33T3G; DPAK2
U4: BU42xx; SSOP-5
U5: NCP1117ST15T3G; DPAK2

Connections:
+1V5: C37.1, U5.2 (VO); also elsewhere on the board
+3.3V: C35.1, R5.2, U3.2 (VO), U4.2 (Vdd), U5.3 (VI); also elsewhere on the board
+5V: C33.1, D2.2 (K), U3.3 (VI); also elsewhere on the board
/FPGA/nRESET: C36.1, R5.1, SW1.2, U4.1 (Vout); also elsewhere on the board
GND: C33.2, C34.2, C35.2, C36.2, C37.2, CON2.2, CON2.3, SW1.1, U3.1 (GND), U4.3 (GND), U5.1 (GND); also elsewhere on the board
unnamed: C34.1, U4.5 (CT)
VIN: CON2.1, D2.1 (A); also elsewhere on the board

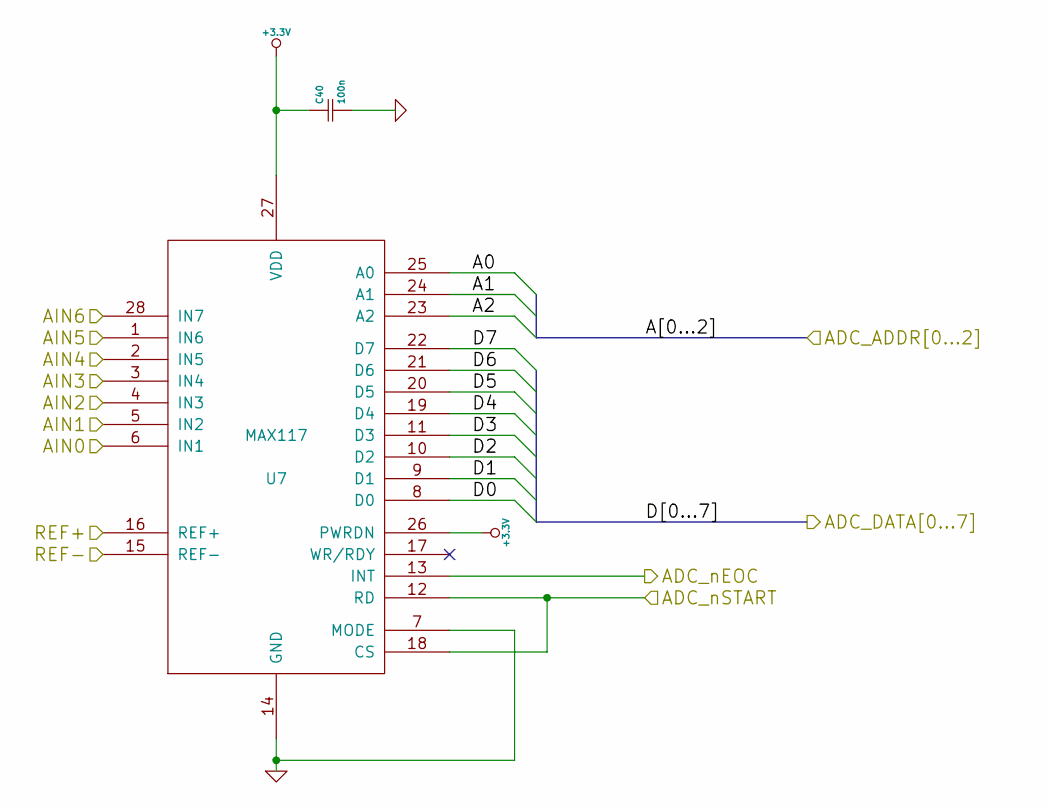
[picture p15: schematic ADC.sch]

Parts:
C40: 100n; c_0805
U7: MAX117; SSOP28

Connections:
+3.3V: C40.1, U7.26 (PWRDN), U7.27 (VDD); also elsewhere on the board
/ADC/A0: U7.25 (A0); also elsewhere on the board
/ADC/A1: U7.24 (A1); also elsewhere on the board
/ADC/A2: U7.23 (A2); also elsewhere on the board
/ADC/ADC_nEOC: U7.13 (INT); also elsewhere on the board
/ADC/ADC_nSTART: U7.12 (RD), U7.18 (CS); also elsewhere on the board
/ADC/AIN0: U7.6 (IN1); also elsewhere on the board
/ADC/AIN1: U7.5 (IN2); also elsewhere on the board
/ADC/AIN2: U7.4 (IN3); also elsewhere on the board
/ADC/AIN3: U7.3 (IN4); also elsewhere on the board
/ADC/AIN4: U7.2 (IN5); also elsewhere on the board
/ADC/AIN5: U7.1 (IN6); also elsewhere on the board
/ADC/AIN6: U7.28 (IN7); also elsewhere on the board
/ADC/REF+: U7.16 (REF+); also elsewhere on the board
/FPGA/ADC_D0: U7.8 (D0); also elsewhere on the board
/FPGA/ADC_D1: U7.9 (D1); also elsewhere on the board
/FPGA/ADC_D2: U7.10 (D2); also elsewhere on the board
/FPGA/ADC_D3: U7.11 (D3); also elsewhere on the board
/FPGA/ADC_D4: U7.19 (D4); also elsewhere on the board
/FPGA/ADC_D5: U7.20 (D5); also elsewhere on the board
/FPGA/ADC_D6: U7.21 (D6); also elsewhere on the board
/FPGA/ADC_D7: U7.22 (D7); also elsewhere on the board
GND: C40.2, U7.7 (MODE), U7.14 (GND), U7.15 (REF-); also elsewhere on the board

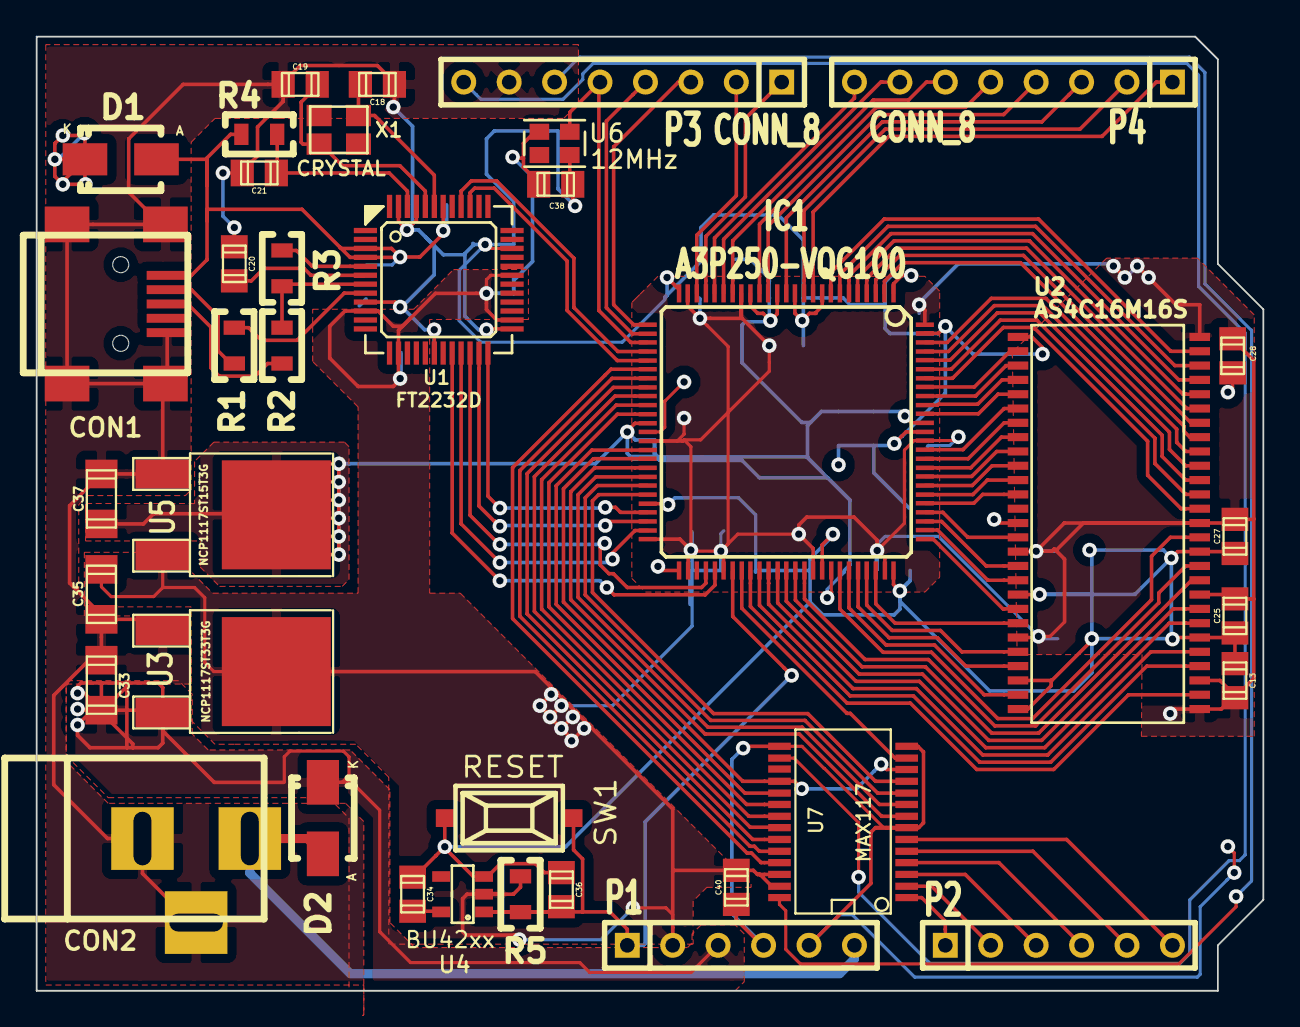
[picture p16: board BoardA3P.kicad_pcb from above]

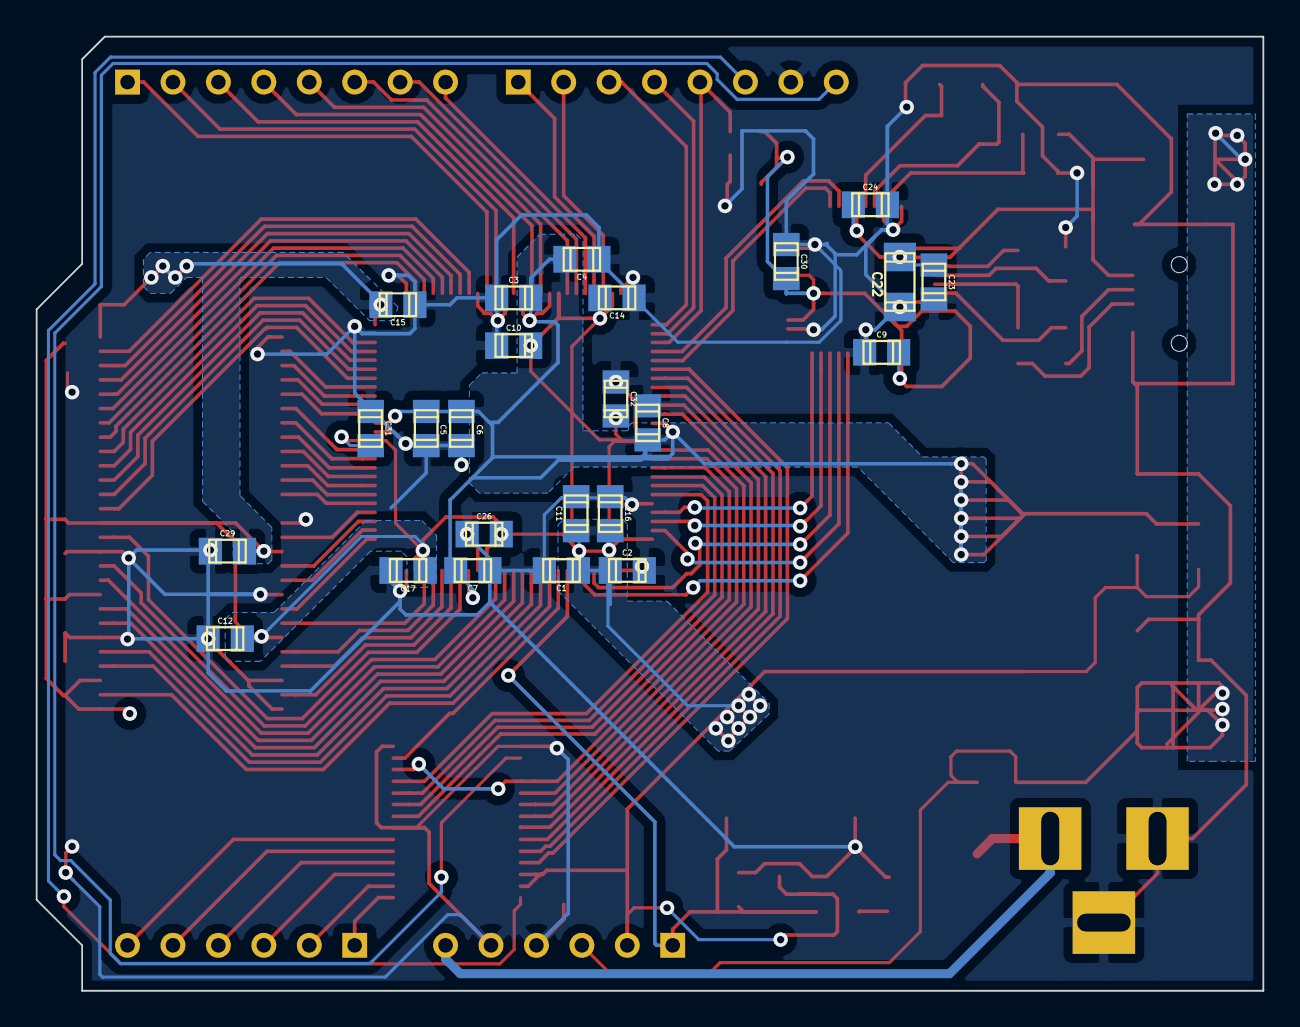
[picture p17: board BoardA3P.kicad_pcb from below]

Board: 2 copper layers, 68.6 x 53.3 mm, 62 parts (24 on the bottom side), 97 nets.

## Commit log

2015-03-25 Added hardware design files (schematic + layout)
    [ADC.sch, BoardA3P.kicad_pcb, BoardA3P.sch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]
2015-03-30 Added readme and a couple of images
2015-04-02 Added LEDs, smaller SDRAM
    [BoardA3P.csv]
